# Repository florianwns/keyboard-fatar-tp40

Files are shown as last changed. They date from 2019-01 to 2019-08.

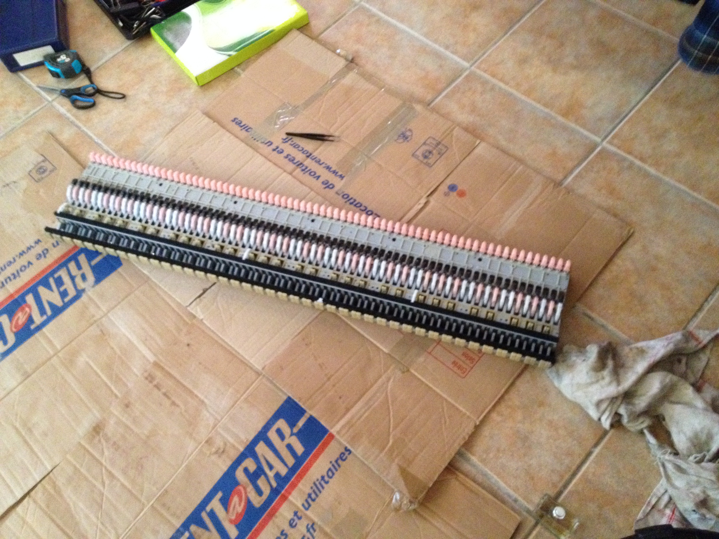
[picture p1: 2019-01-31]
images/IMG_2007.jpg

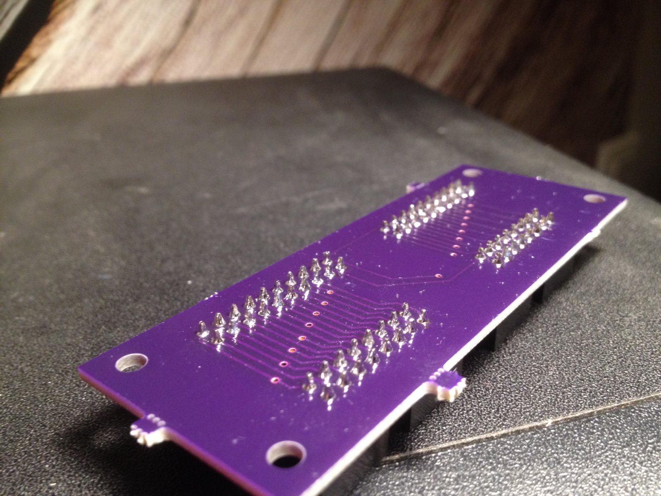
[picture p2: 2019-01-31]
images/IMG_1291.JPG.jpeg

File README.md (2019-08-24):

# DIY - CUSTOM KEYBOARD - FATAR TP/40L

Voici quelques notes de travail sur la construction d'un contrôleur MIDI en me servant de la base d'un FATAR TP/40L récupéré sur un Kurzweil PC3X.

J'ai grâce au projet Open-Source MIDIBOX NG, réussi à créer mon propre clavier maître.
Le tout fonctionne à la perfection, mais demande d'y consacrer pas mal de temps.

## MIDIBOX NG 

Il existe plusieurs projet MIDIBOX mais j'ai choisi MIDIBOX NG car j'avais besoin de modifier la courbe de vélocité du clavier, ce qui n'était pas possible avec le projet MIDIBOX KB.

Vous trouverez toute les infos nécessaires sur la page du projet : http://www.ucapps.de/midibox_ng.html
et aussi sur le forum : http://midibox.org/forums/

## INSTALLATION SUR MAC OS

Avant d'installer le logiciel MIOS STUDIO (http://www.ucapps.de/mios_studio.html) qui permet de configurer la carte électronique et de charger le firmware, vous devez sous MAC démarrer avec CMD+R et dans le terminal faire un 'csrutil disable', sinon la carte ne sera pas reconnu par MAC OS.

Après il vous suffit d'installer le firmware, et de charger votre fichier de configuration qui sera stocké sur la carte SD. 

## FATAR TP/40L

J'ai eu besoin de 3 cartes électroniques pour réaliser ce projet : 

- "MIDIbox Core STM32F4 PCB" qui accueille le STM32F4 (https://modularaddict.com/manufacturer/midibox/midibox-core-stm32-pcb)
- "MIDIbox DIO Matrix PCB" qui permet de relier les matrices de leds (https://modularaddict.com/manufacturer/midibox/midibox-diomatrix-pcb)
- et la dernière qui rend compatible le "MIDIbox DIO Matrix PCB" avec le clavier Fatar TP40, vous devrez la faire imprimer, mais le PCB est dispo ici : http://www.midibox.org/dokuwiki/doku.php?id=fantomxr
Elle a été créée par un membre de la communauté MIDIBOX, FantomXR que je remercie grandement .

Dans mon cas, j'ai découpé le clavier FATAR pour qu'il ne fasse plus que 72 touches, cela ne pose pas de soucis majeurs, mais faites attention à ne pas découper les matrices de leds, sinon faudra resouder tout ça ;) 

Pour info, voici un thread intéressant où l'on trouve la liste des touchers piano par modèle de clavier : https://www.gearslutz.com/board/electronic-music-instruments-and-electronic-music-production/1149168-ultimate-keybed-thread-models-manufacturers-listed.html

## CONNECTIQUES

Mon clavier maître est relativement simple puisqu'on peut y brancher une pédale de sustain et une pédale d'expresion. J'ai choisi deux pédales M-audio (SP-2  et EX-P) qui ne sont pas chères et super pratiques, car on peut choisir le type de branchement en fonction du constructeur. Le système MIDIBOX étant modulaire, on peut très bien imaginer, rajouter par la suite des potards, une modulation, des LCDs, etc...

Il suffira soit de connecter un Module AINSER64 (http://www.ucapps.de/mbhp_ainser64.html), soit d'utiliser le connectiques restantes sur les broches J5A et J5B.

Petite Astuce : Si vous alimenter votre carte en USB comme moi, la tension n'est pas forcément très stable et du coup le contrôleur envoie beaucoup de messages MIDI car les valeurs varient avec la tension. Du coup il existe une petite technique pour lisser les valeurs et éviter les variations, c'est de mettre un condensateur de 100nf entre la masse et l'entrée analogique au plus proche du contrôleur.

Ah aussi il faut le savoir les pédales d'expression sont alimentés en 3.3 volt ;) 

## COURBE DE VÉLOCITÉ

Mon plus gros soucis, lors de la création du contrôleur a été la vélocité du clavier. Elle ne me correspondait pas vraiment, du coup j'ai mis au point une petite technique pour la corriger.

Par défaut, j'ai mis une courbe de vélocité linéaire dans mon fichier de configuration .NGC, puis j'ai installé la démo gratuite de Pianoteq, et j'ai testé plusieurs courbes correctrices de vélocité disponibles sur le site de Pianoteq (https://www.pianoteq.com/velocity_curves). Une fois ma courbe de vélocité trouvée dans Pianoteq, j'ai codé un petit programme en python pour convertir les courbes de vélocité Pianoteq au format MIDIBOX NG et je l'ai rentrée dans mon fichier de configuration.

Je me suis aussi servi de MIDI MONITOR (https://www.snoize.com/MIDIMonitor/) pour vérifier que j'arrivait bien à obtenir une vélocité bien équilibrée sur l'ensemble des 128 niveaux.

## REMERCIEMENT

Je voudrais remercier 'Thorsten Klose' pour son magnifique projet sans qui rien ne serait possible, et 'FantomXR' sans qui je n'aurais pas pu connecter mon fatar et dont les topics ont rendus ce projet un peu plus réaliste à mes yeux. Merci aussi à toute cette communauté bienveillante de geeks bricoleurs  qui m'a donné la force d'aller au boût de ce projet. Merci surtout à l'élue de mon coeur qui a écouté chacunes de mes idées folles et m'a soutenu sans jamais sourciller. Merci !!

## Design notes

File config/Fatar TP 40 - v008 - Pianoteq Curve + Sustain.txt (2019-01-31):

RESET_HW

# reduce number of SRs for faster scan
# with 2 SRs the scan takes ca. 500 uS instead of 2.5 mS
SRIO num_sr=2

# AIN hardware, for pedal connection
AIN enable_mask=110000
EVENT_AIN id=1 type=CC chn=1 cc=64 ain_mode=Switch range=0:127
EVENT_AIN id=2 type=CC chn=1 cc=11 ain_mode=Direct range=0:127

# You can invert 127:0 for sustain pedal with opened contact
# EVENT_AIN id=1 type=CC chn=1 cc=64 ain_mode=Switch range=127:0

# keyboard configuration
KEYBOARD n=1   rows=12  dout_sr1=1  dout_sr2=2  din_sr1=1  din_sr2=2 \
               din_inverted=0  break_inverted=0  din_key_offset=40 \
               scan_velocity=1 scan_optimized=1  note_offset=21 \
               delay_fastest=55  delay_fastest_black_keys=29  delay_slowest=300 \
               make_debounced=0

# using an interpolation map to define the velocity curve
# Compute with Pianoteq and translate with my program in python
# Velocity = [0, 94, 105, 116, 123, 126; 3, 71, 80, 94, 109, 127]
MAP1/BYTEI  0:3 94:71 105:80 116:94 123:109 126:127

# send MIDI event with mapped velocity value
EVENT_KB id=1  type=NoteOn chn=1 key=any use_key_number=1 range=0:127  kb_velocity_map=map1  kb_transpose=0

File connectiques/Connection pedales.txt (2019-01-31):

            +-------------------------------------------------+
            | Connecter une pédale d'expression et de sustain |
            +-------------------------------------------------+

# Pédale d'expression "M-audio EX-P"  :

  - En Mode "M-Audio" sur la pédale, on connecte les fils comme ceci :

                          Jack Stéréo
            +---------------------------------------+
            |          Tip          Sleeve          |
            |           |             |             |
            |           v             v             |
            |       --+-----------------------+     |
            |     /   |    |    |             |     |
            |     \   |    |    |             |     |
            |       --+-----------------------+     |
            |                ^                      |
            |                |                      |
            |               Ring                    |
            +---------------------------------------+

    ° Tip    -> Ground
    ° Ring   -> 3.3 V
    ° Sleeve -> Input Analog

    Le problème c'est qu'au branchement cela crée un court circuit,
    il faut donc allumer le controleur une fois que les branchement sont fait,
    il n'y a pas de protection contre cela.

  - Autre Solution, en Mode "Other" :

    On branche en inversant le 3.3 v et l'input analog

    ° Tip    -> Ground
    ° Ring   -> Input Analog
    ° Sleeve -> 3.3 V

  - Astuce (smooth outlying data): Si la tension de 3.3v n'est pas stable
  alors il va subvenir des variations, il faut donc placer un condensateur
  de 100 nf entre le ground et l'input analog pour adoucir les variations
  à la sortie. il faut la placer au plus près du controleur sinon sur le jack.

# Pédale de sustain "M-audio SP-2"  :

                              Jack Mono
                +----------------------------------+
                |          Tip          Sleeve     |
                |           |             |        |
                |           v             v        |
                |       --+------------------+     |
                |     /   |    |             |     |
                |     \   |    |             |     |
                |       --+------------------+     |
                |                                  |
                +----------------------------------+

  Il faut brancher une résistance de 10k ohm entre le Ground et l'input analog
  La pédale possède deux modes, les controleur MIDI acceptent
  soit un contact ouvert soit un contact fermé.

                   10 K ohm <- Ground
                   |
                   v
    ° Tip    -> Input Analog
    ° Sleeve -> Ground

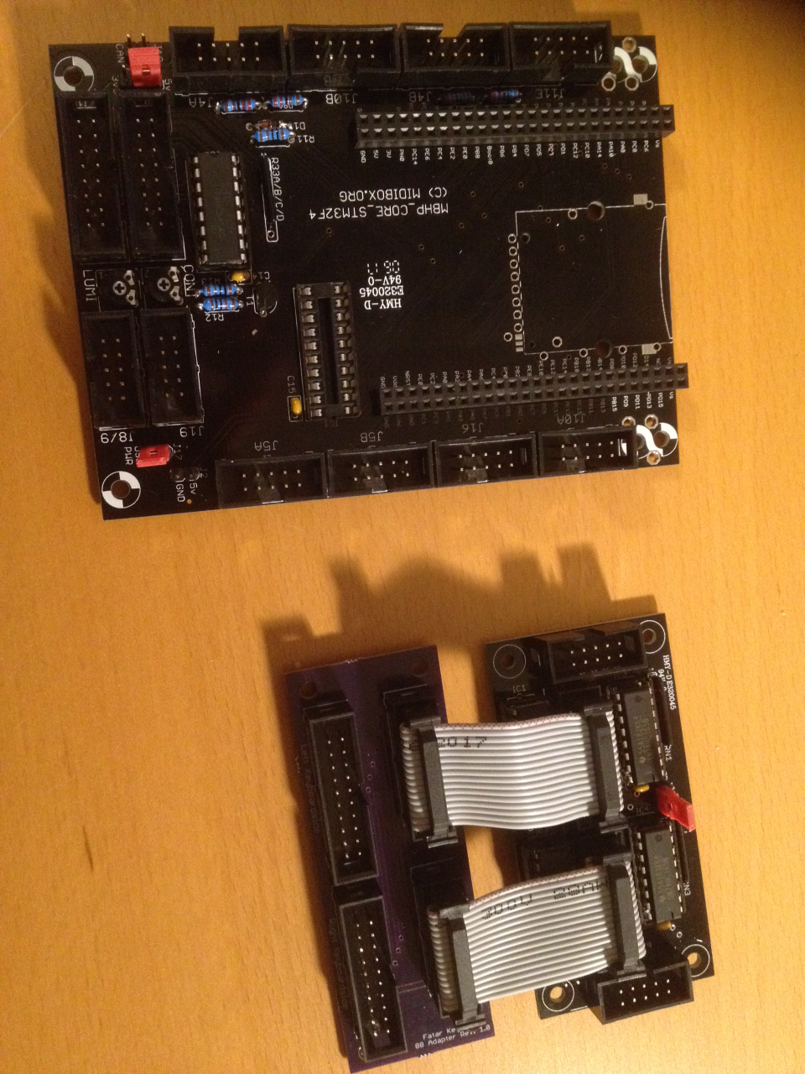
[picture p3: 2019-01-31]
images/IMG_1294.JPG.jpeg

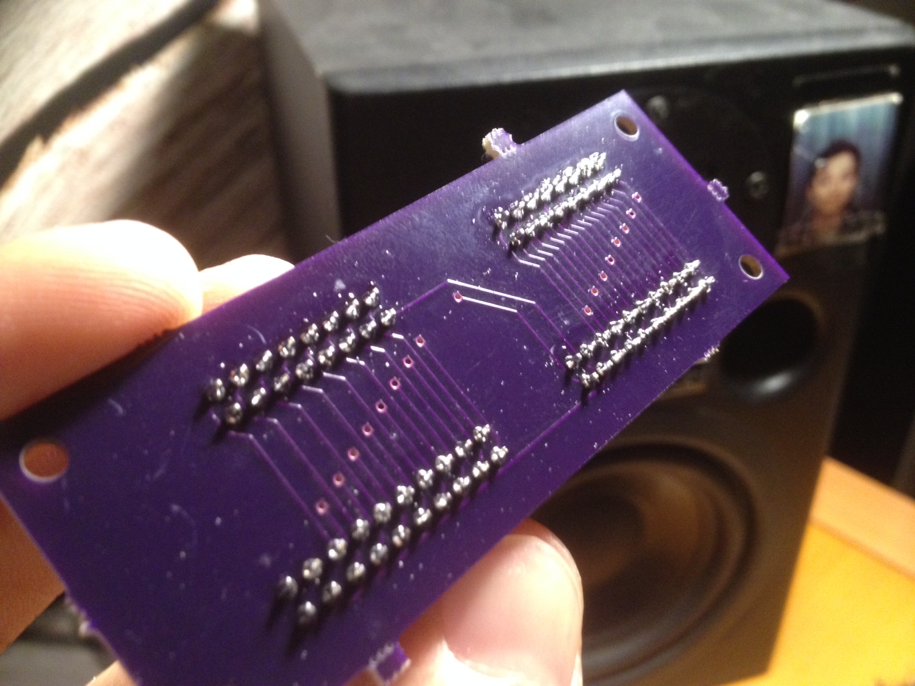
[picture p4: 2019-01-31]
images/IMG_1292.JPG.jpeg

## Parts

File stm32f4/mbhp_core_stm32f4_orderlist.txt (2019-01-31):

To english readers: since I only have experience with german mailorder 
distributors, this list is mainly dedicated for users from Germany

------------------------------------------------------------------------------

MBHP Core STM32F4 Orderlist (last update: 01-2014)
~~~~~~~~~~~~~~~~~~~~~~~~~~~~~~~~~~~~~~~~~~~~~~~~~~

All prices in EUR (Euro)
Exchange rates: see http://www.xe.com

at http://www.reichelt.de
+----------------------------------------------+-------+--------------------+-------+--------+
| Description                                  | Qty   | Part #             | Price | Total  |
+----------------------------------------------+-------+--------------------+-------+--------+
| Diode 1N4148                                 |     1 | 1N 4148            |  0.02 |   0.02 |
| Transistor BC337                             |     1 | BC 337-16          |  0.06 |   0.06 |
| 74HC595                                      |     1 | 74HC 595           |  0.30 |   0.30 |
| IC-Socket for 74HC595                        |     1 | GS 16              |  0.04 |   0.04 |
| 74HCT541                                     |     1 | 74HCT 541          |  0.20 |   0.20 |
| IC-Socket for 74HCT541                       |     1 | GS 20              |  0.04 |   0.04 |
| Ceramic Cap 100 nF                           |     2 | Z5U-2,5 100n       |  0.06 |   0.12 |
| Resistor 10 kOhm                             |     1 | 1/4W 10k           |  0.03 |   0.03 |
| Resistor 1 kOhm                              |     2 | 1/4W 1.0k          |  0.03 |   0.06 |
| Resistor 2.2 kOhm                            |     4 | 1/4W 2.2k          |  0.03 |   0.12 |
| Resistor Network 4*1 kOhm (1 common pin)     |     1 | SIL 5-4 1,0K       |  0.08 |   0.08 |
| TrimmPot 10 k                                |     2 | PT 6-L 10K         |  0.22 |   0.44 |
| 2x5 DIL Headers (German: "Wannenstecker")    |    10 | WSL 10G            |  0.08 |   0.80 |
| 2x5 DIL Sockets (German: "Pfostenbuchse")    |    10 | PFL 10             |  0.08 |   0.80 |
| 2x8 DIL Headers (German: "Wannenstecker")    |     2 | WSL 16G            |  0.07 |   0.14 |
| 2x8 DIL Sockets (German: "Pfostenbuchse")    |     2 | PFL 16             |  0.09 |   0.18 |
| 1-row SIL Headers (9 pins required)          |     1 | SL 1X40G 2,54      |  0.18 |   0.18 |
| 2-row SIL Headers (2 2x25 pins required)     |     2 | BL 2X25G 2,54      |  1.40 |   2.80 |
| Jumpers                                      |     2 | JUMPER 2,54GL RT   |  0.05 |   0.10 |
| Ribbon cable 3 meters                        |     3 | AWG 28-16G         |  0.66 |   1.98 |
| Micro-USB B Cable for USB-MIDI connection    |     1 | AK 676-AB2         |  2.10 |   2.10 |
+----------------------------------------------+-------+--------------------+-------+--------+
Note 1: the ribbon cable is listed for people who don't have alread cable at home ;-)
Note 2: DIL sockets for interconnection to other modules. It makes sense to order more
        (e.g. 10 pieces)
Note 3: outside europe the BC337 is hard to find, the 2N3904 is a good replacement
        But note that the outer pins (E and C) are exchanged - you have to upturn the
        transistor to get the E, B, C pin matching with the PCB
Note 4: Reichelt doesn't sell the STM32F4DISCOVERY module
        Shops are listed under http://www.ucapps.de/mbhp_core_stm32f4.html
Note 5: Reichelt doesn't sell the 3M SD Card Socket
        Can be ordered at Mouser - SD-RSMT-2-MQ

tk@midibox.org

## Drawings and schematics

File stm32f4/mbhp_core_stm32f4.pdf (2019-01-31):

## Vs Vd

MI1

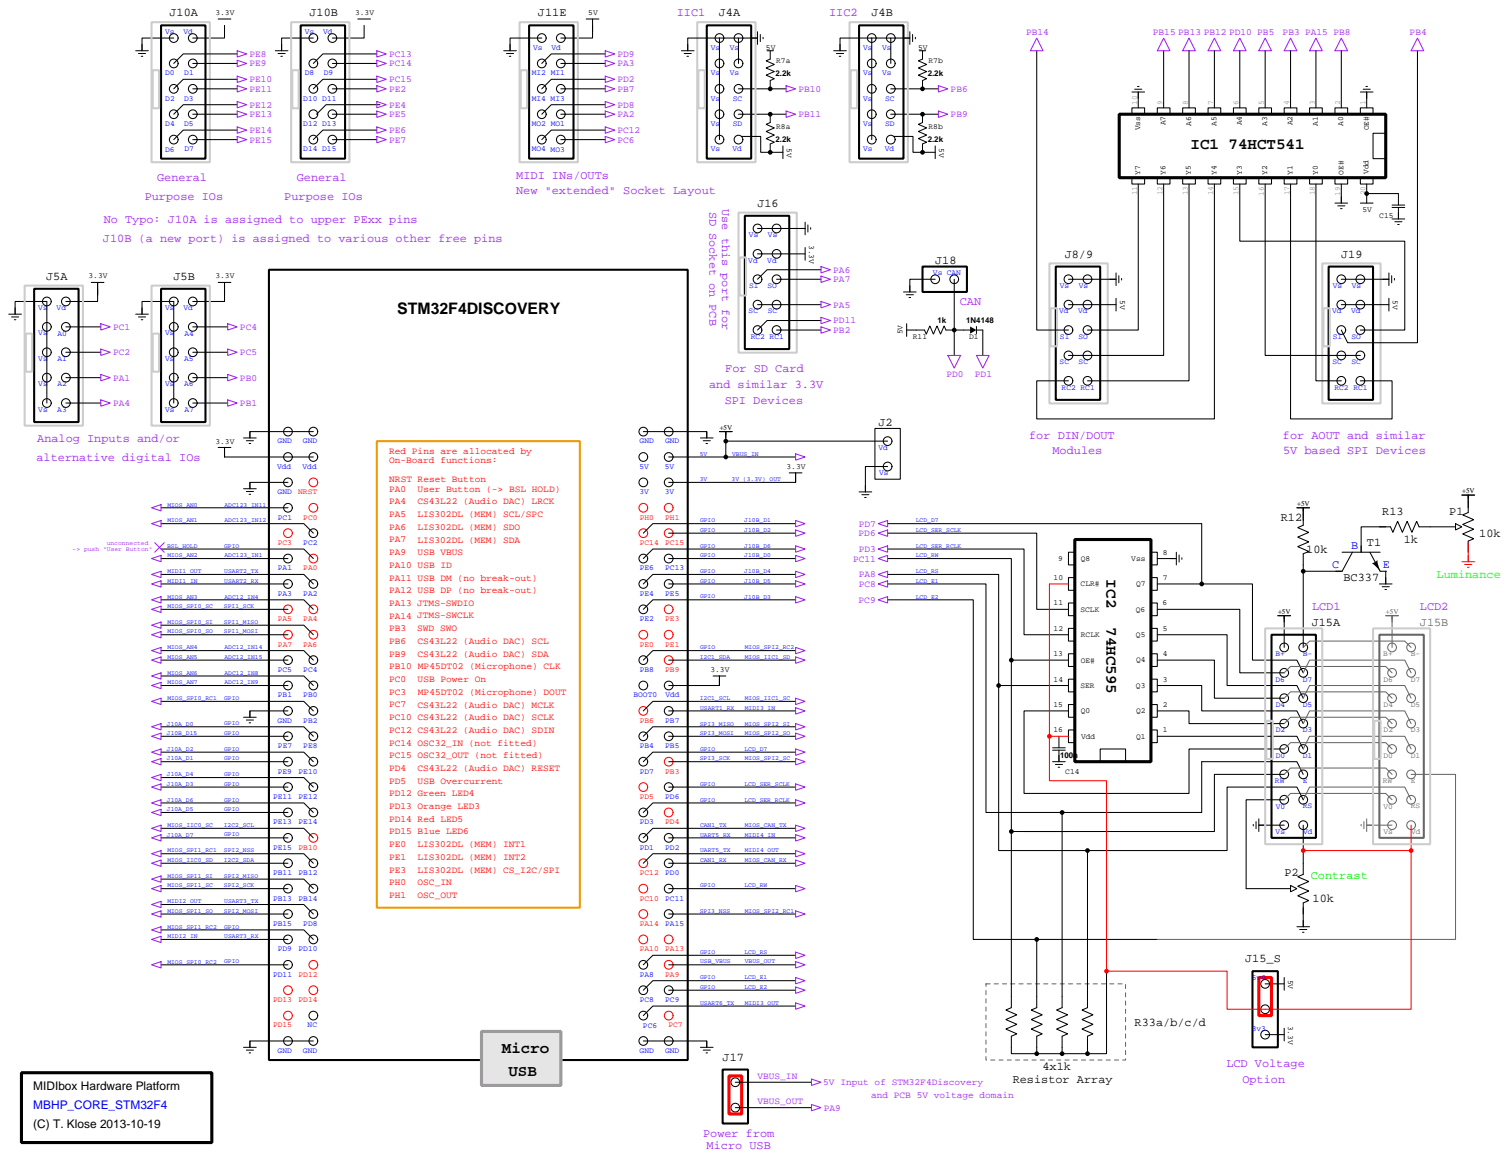
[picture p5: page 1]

Use this port for Vs Vd

No Typo: J10A is assigned to upper PExx pins
J10B (a new port) is assigned to various other free pins

SD Socket on PCB

Analog Inputs and/or
alternative digital IOs

for AOUT and similar
5V based SPI Devices

and PCB 5V voltage domain

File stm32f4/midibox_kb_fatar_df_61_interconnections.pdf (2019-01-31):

# MBHP_DIO_MATRIX

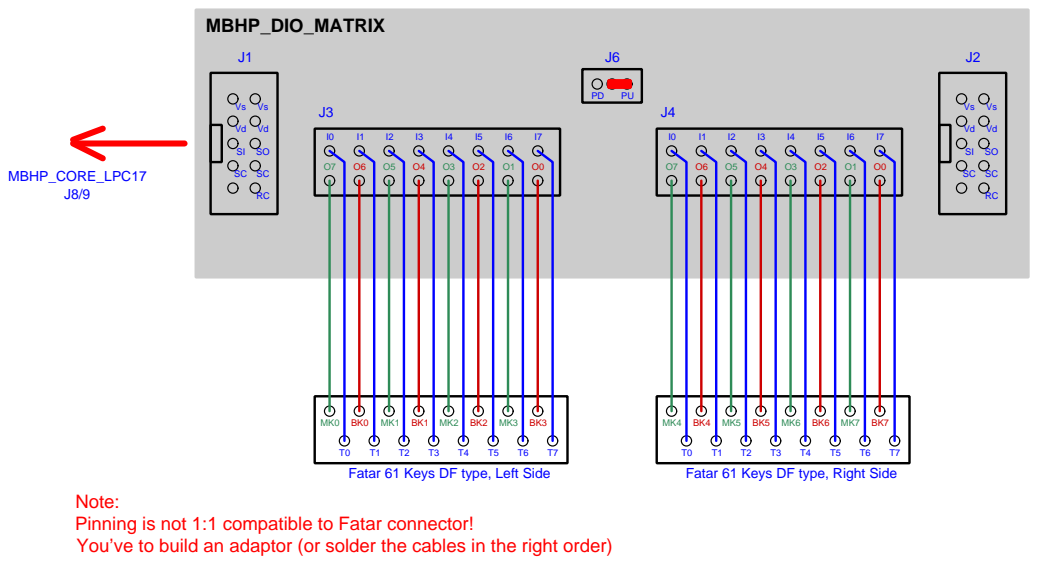
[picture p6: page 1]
Fatar 61 Keys DF type, Left Side; Fatar 61 Keys DF type, Right Side; MBHP_CORE_LPC17 J8/9

Note:
Pinning is not 1:1 compatible to Fatar connector!
You’ve to build an adaptor (or solder the cables in the right order)

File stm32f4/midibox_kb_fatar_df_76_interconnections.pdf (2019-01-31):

J1 | J6 | J2

# MBHP_DIO_MATRIX

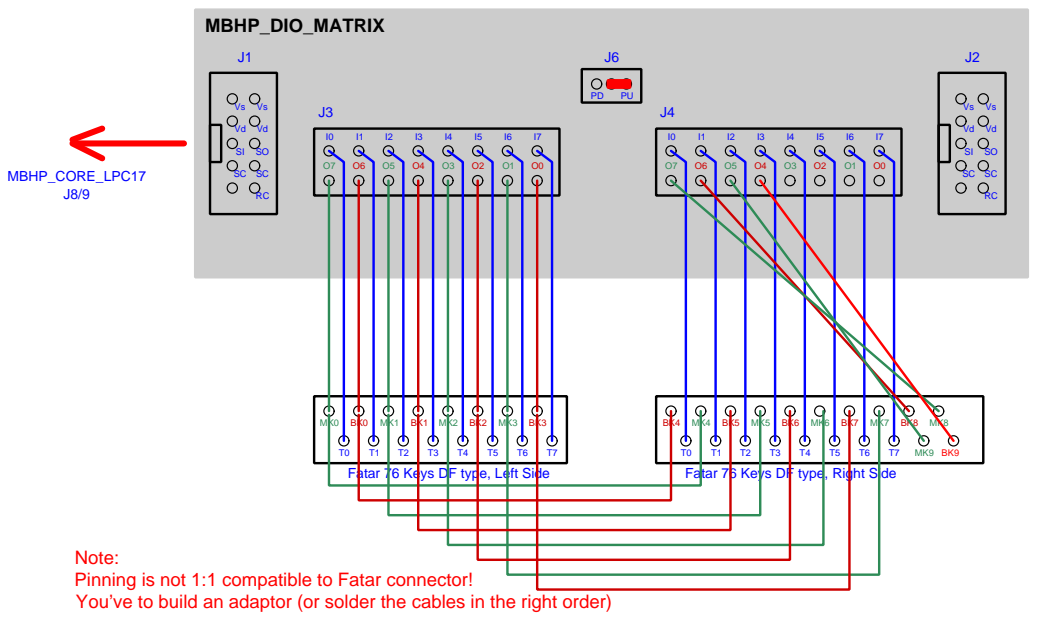
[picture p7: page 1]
MBHP_CORE_LPC17 J8/9

Fatar 76 Keys DF type, Left Side

Fatar 76 Keys DF type, Right Side

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

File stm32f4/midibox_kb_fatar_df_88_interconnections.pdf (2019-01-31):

J1 | J6 | J2

# MBHP_DIO_MATRIX

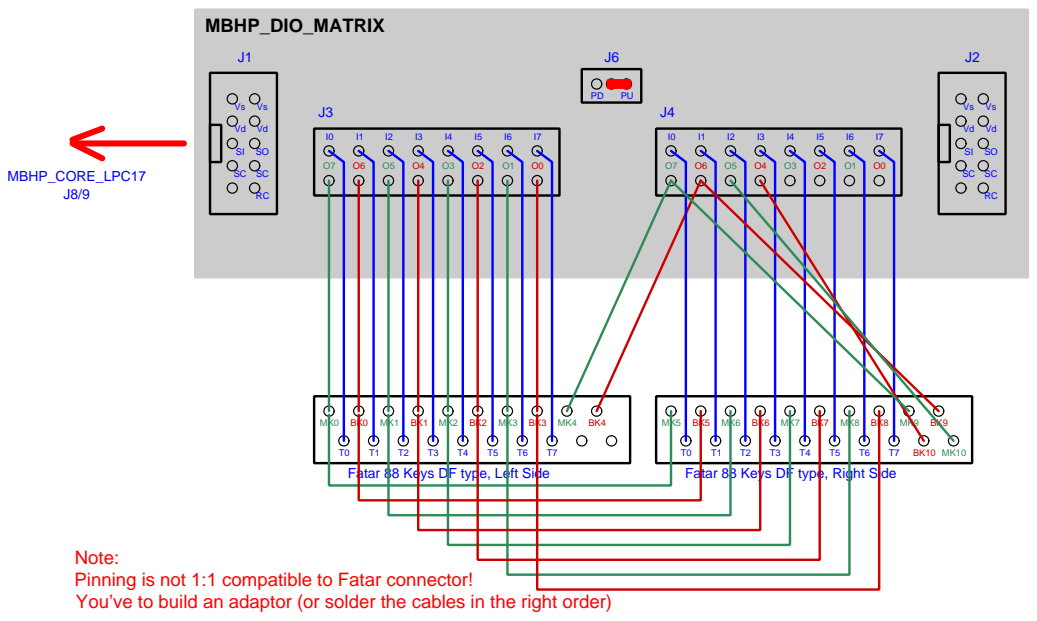
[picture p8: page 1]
MBHP_CORE_LPC17 J8/9

Fatar 88 Keys DF type, Left Side

Fatar 88 Keys DF type, Right Side

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

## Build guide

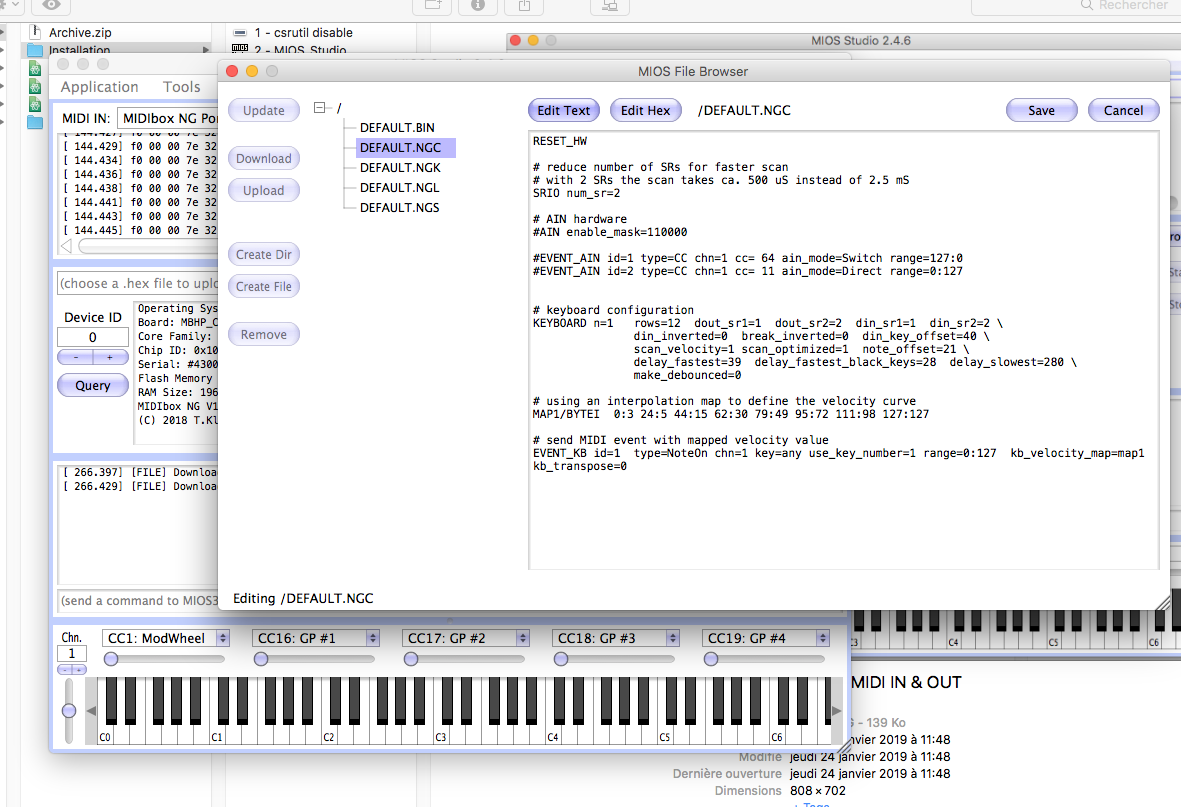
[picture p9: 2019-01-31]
installation/4 - Update then edit NGC.png

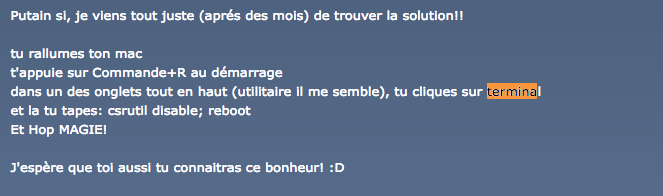
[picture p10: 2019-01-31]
installation/1 - csrutil disable.png
